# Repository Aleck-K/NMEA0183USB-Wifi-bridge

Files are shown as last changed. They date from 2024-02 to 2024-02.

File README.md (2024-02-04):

NMEA0183USB-Wifi-bridge on ESP8266 microcontroller
  
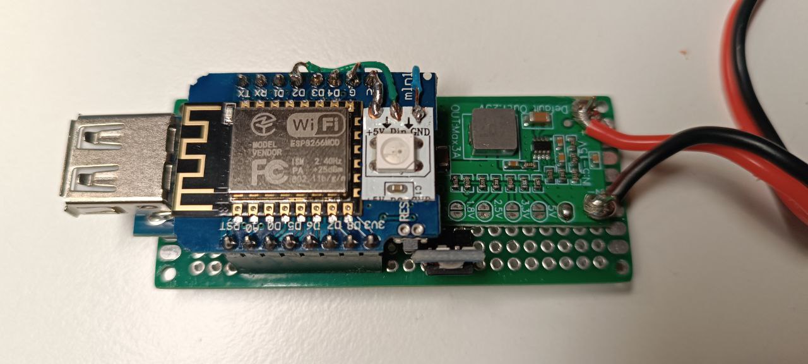
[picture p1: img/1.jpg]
</td>

The idea behind the project is to use perhaps the cheapest Matsutec AR-10 AIS receiver on the market to transmit NMEA messages to Navionics. Navionics perfectly supports receiving messages via a Wifi network. The device is a bridge between the Matsutec AR-10 (or any other USB device running on the CH340 chip) and WiFi. In addition, NMEA messages received from USB are duplicated into the USB port of the microcontroller board; the device can be connected to a computer to transmit messages to, for example, OpenCPN. Also, messages coming to the USB of the microcontroller are sent to WiFI.

The project code is based on the code of the following projects:

https://github.com/alvra/nmea-bridge - read the annotation to understand all the capabilities of the device.
https://github.com/UNBIduino/USBHostSeildWithCH340 - driver for CH340 chip

To assemble the device, no special knowledge or skills in electronics are required. The device is assembled from ready-made components:
1. ESP8266 WeMos D1 Mini V2 (ESP-12)
2. Mini USB Host Shield
3. Power converter 12-5v TZT 3A
4. Power converter 5-3.3v GSMIN AMS1117 800mA
5. Breadboard 3x7cm
6. Optional: 1 addressable LED WS2812B or similar
7. 4 screws 2.2x4.5 fastening the board, 4 screws 4.5x20 for the case

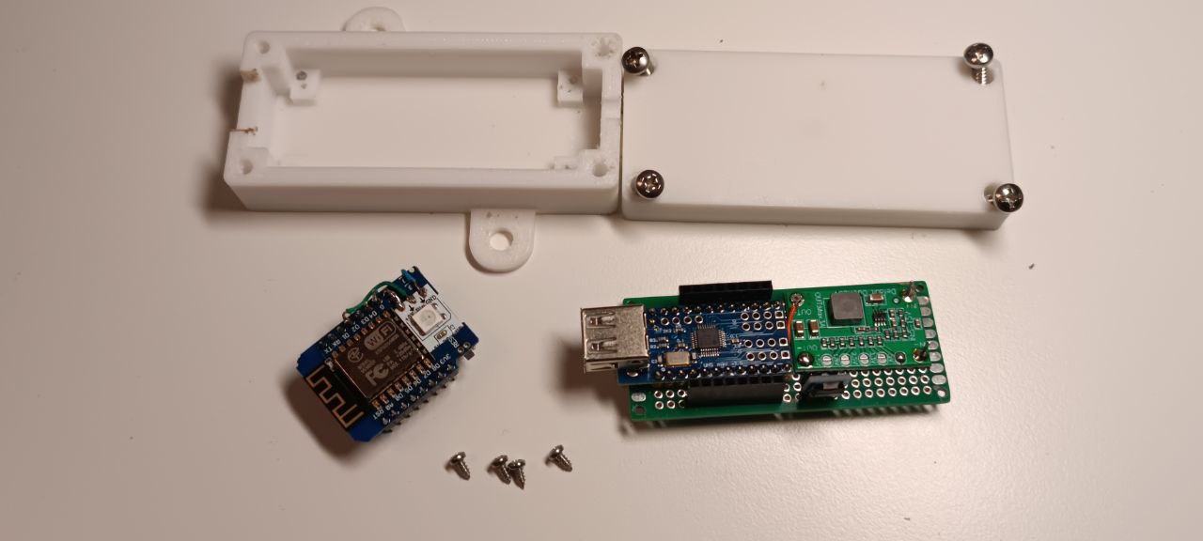
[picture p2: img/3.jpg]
</td>
 
Connection diagram here:
https://oshwlab.com/aleck1/new-project
Please note the following during assembly:
* it is necessary to supply 5v power to the VBUS pin of the Mini USB Host Shield board, otherwise the AR-10 will not work. Most likely, to do this, you need to cut the track going to the VBUS pin and solder the conductor to the 5v power supply directly to the pin. Read more about the problem and its solution here: https://www.hackster.io/usini/plug-any-usb-device-on-an-esp8266-e0ca8a (Fix Powering Issues)
* Mini USB Host Shield is placed asymmetrically on a 3x7cm breadboard. I recommend moving it one row to the right. This will provide more space for conductors to WEMOS. The case is also designed with this displacement in mind.
* In order for everything to fit on a 3x7cm breadboard, the Mini USB Host Shield must be placed on the first row of the board
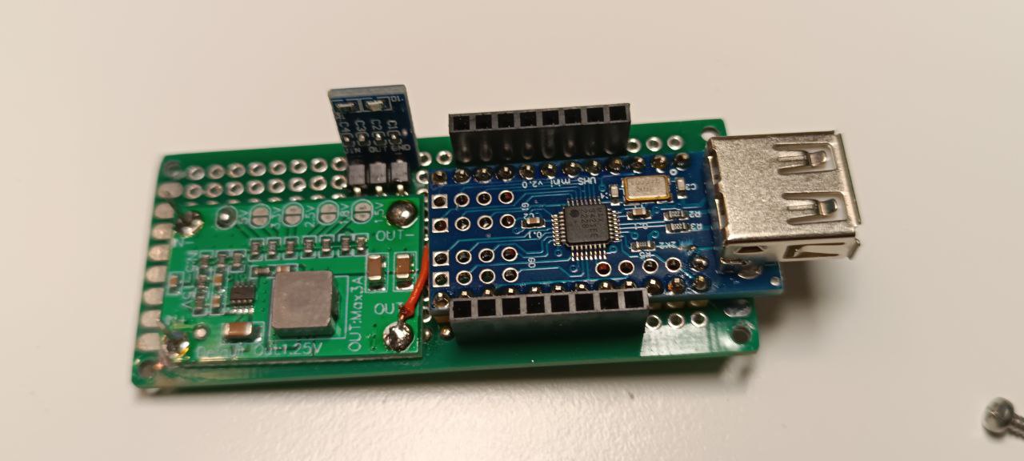
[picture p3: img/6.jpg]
</td>
* The ESP8266 WeMos D1 Mini microcontroller is placed ABOVE the Mini USB Host board on a high comb starting from the 4th row. Typically this comb comes with WeMos D1
* Although the device works without a 5-3.3v power converter, it is still better to use it, because the WEMOS power on the 3.3v pin may not be enough for stable operation

An optional WS2812B addressable LED is used to provide better visibility into device operating status. It can be glued directly to the WeMos D1 board, control pin D2. It signals the following:
* red: USB initialization or reading error
* blue: double blinking every 15 seconds - working in access point mode, single blinking - working in wifi client mode, constantly on - wifi initialization error
* green: NMEA message received and processed via USB
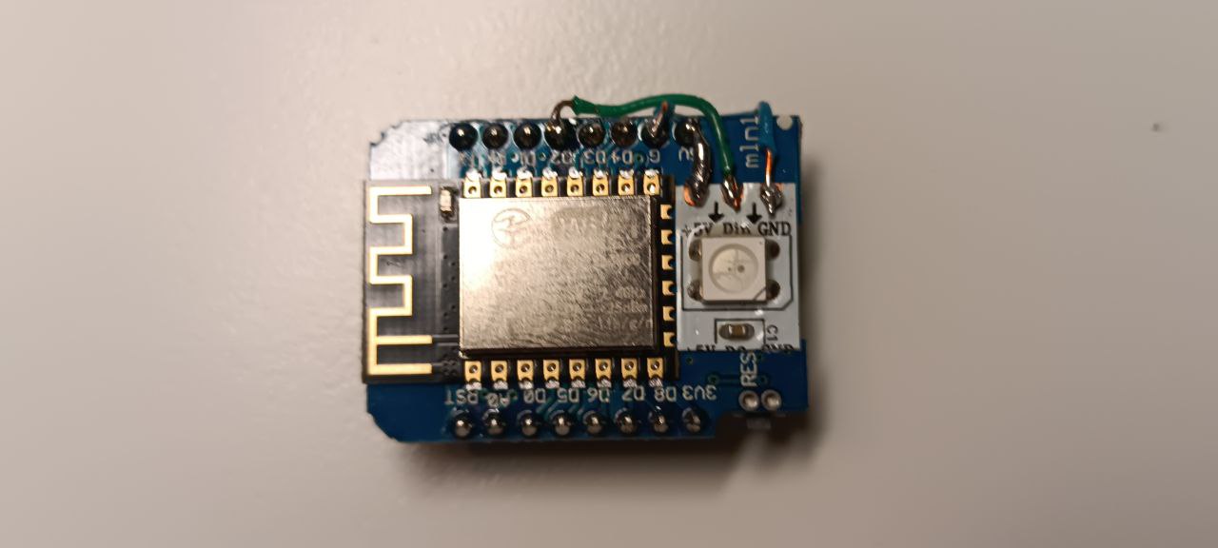
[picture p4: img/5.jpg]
</td>

You can do without an addressable LED. In this case, the indication is by the built-in LED: double blinking every 15 seconds - working in access point mode, single blinking - working in wifi client mode, constantly lit - wifi initialization error. Be sure to comment out (delete) the line in the sketch #define RGB_LED to enable indication mode with built-in LED.

Please note: The current version does not support hot plugging of the AR-10 to USB. AIS must be connected before the device is powered on.

Case layout for printing on a 3D printer in the Box_design catalog. Ears are provided for surface mounting.

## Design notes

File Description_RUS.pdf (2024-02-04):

NMEA0183USB-Wifi-bridge на микроконтроллере ESP8266

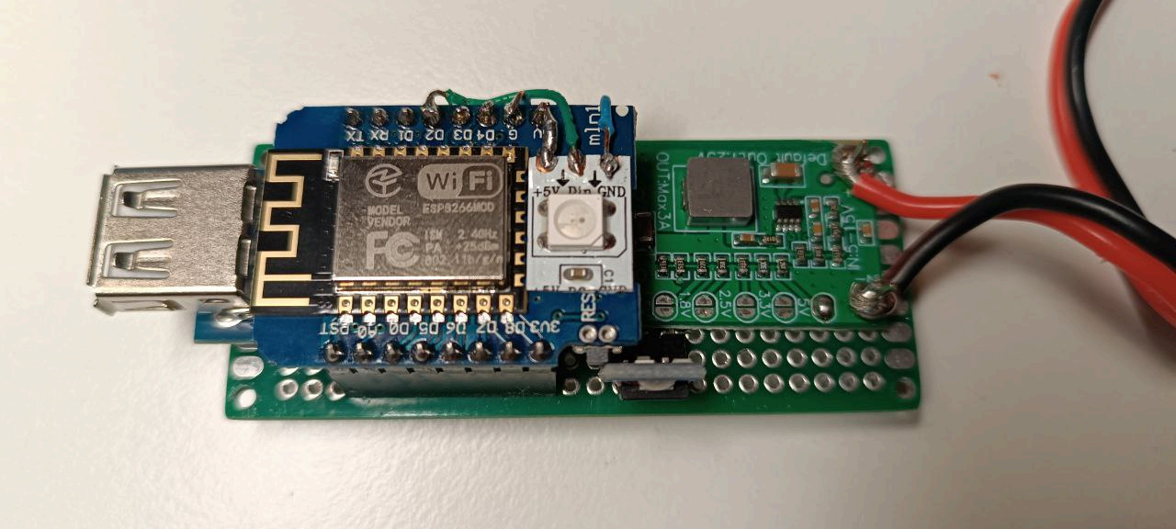
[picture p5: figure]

Идея проекта - использовать, пожалуй, самый дешевый на рынке AIS приемник Matsutec AR-10 для передачи сообщений NMEA в Navionics. Навионикс отлично поддерживает получение сообщений через сеть Wifi. Устройство является мостом между Matsutec AR-10 (или любым другим USB устройством, работающем на чипе CH340) и WiFi. Кроме того, сообщения NMEA, полученные с USB, дублируются в USB порт платы микроконтроллера, устройство может быть подключено к компьютеру для передачи сообщений в, например, OpenCPN. Также сообщения, приходящие в USB микроконтроллера, пересылаются в WiFI.

Код проекта основан на коде следующих проектов: https://github.com/alvra/nmea-bridge - прочитайте анотацию, чтобы понять все возможности устройства.
https://github.com/UNBIduino/USBHostSeildWithCH340 - драйвер для чипа CH340

Для сборки устройства не требуется особых знаний и навыков в электронике. Устройство собирается из готовых компонентов:
1. ESP8266 WeMos D1 Mini V2 (ESP-12)
2. Mini USB Host Shield
3. Конвертер питания 12-5v TZT 3A
4. Конвертер питания 5-3.3v GSMIN AMS1117 800мА
5. Макетная плата 3х7см
6. Опционально: 1 адресный светодиод WS2812B или аналогичный
7. 4 шурупа 2.2х4.5 крепление платы, 4 шурупа 4.5х20 для корпуса

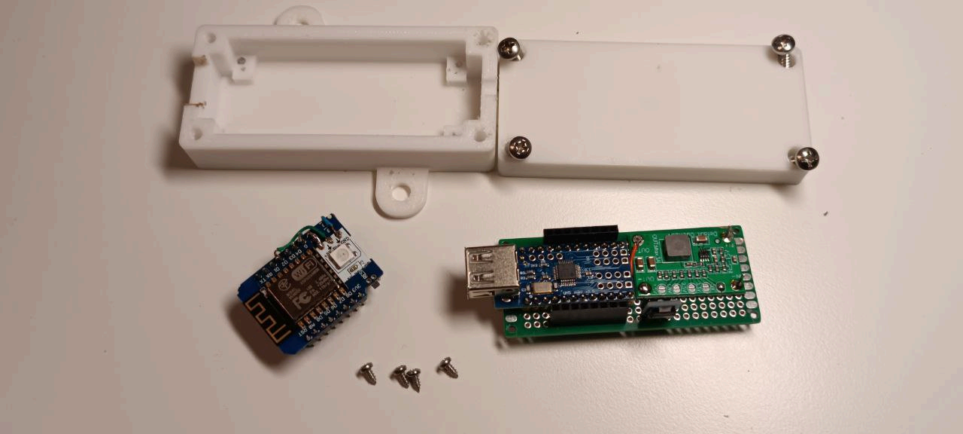
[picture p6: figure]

Схема соединений здесь:
https://oshwlab.com/aleck1/new-project
При сборке необходимо учесть следующее:
- необходимо подать питание 5v на пин VBUS платы Mini USB Host Shield, иначе AR-10 работать не будет. Скорее всего, для этого необходимо перерезать дорожку, идущую к пину VBUS и припаять проводник к 5v питанию напрямую на пин. Подробнее о проблеме и ее решении здесь: https://www.hackster.io/usini/plug-any-usb-device-on-an-esp8266-e0ca8a (Fix Powering Issues)
- Mini USB Host Shield размещается на макетной плате 3х7см несимметрично. Рекомендую сдвинуть его на один ряд вправо. Так будет больше места для проводников к WEMOS. Корпус тоже спроектирован с учетом такого смещения.
- Чтобы все поместилось на макетную плату 3х7см, размещать Mini USB Host Shield надо с первого ряда платы

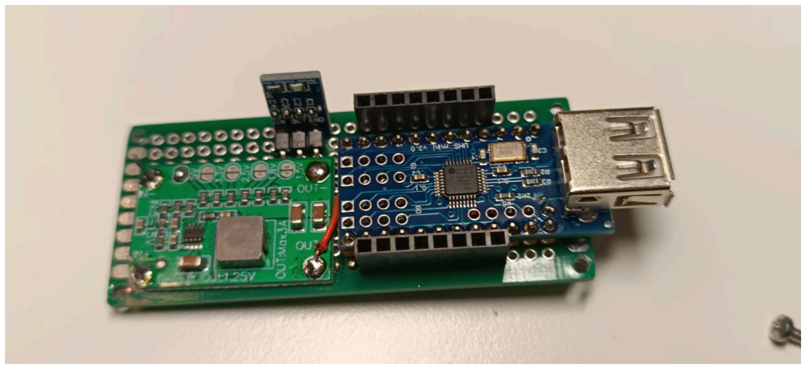
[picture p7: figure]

- Микроконтроллер ESP8266 WeMos D1 Mini размещается НАД платой Mini USB Host на высокой гребенке начиная с 4 ряда. Обычно такая гребенка идет в комплекте с WeMos D1

- Хотя устройство работает и без Конвертера питания 5-3.3v, лучше все же его использовать, т.к. мощности WEMOS на пине 3.3v может не хватать для стабильной работы

Опциональный адресный светодиод WS2812B используется для лучшего представления о статусе работы устройства. Его можно приклеить прямо на плату WeMos D1, управляющий пин D2. Он сигнализирует следующее:
- красный: ошибка инициализации или чтения USB
- синий: двойное мигание раз в 15 сек - работа в режиме точки доступа, одиночное мигание - работа в режиме wifi клиента, горит постоянно - ошибка инициализации wifi
- зеленый: получено и обработано сообщение NMEA по USB

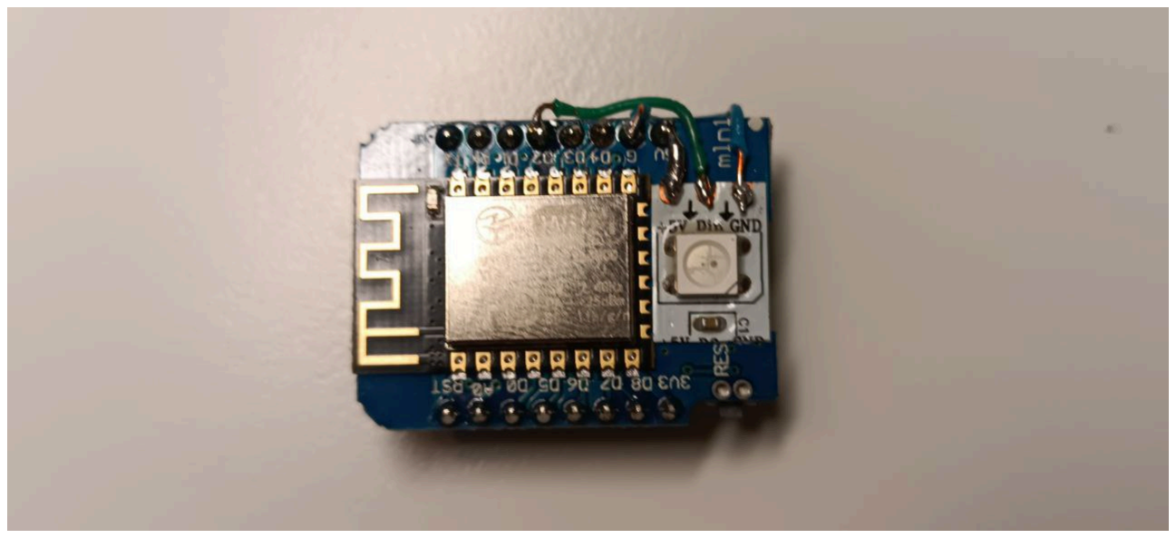
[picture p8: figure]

Можно обойтись без адресного светодиода. В этом случае индикация происходит встроенным светодиодом: двойное мигание раз в 15 сек - работа в режиме точки доступа, одиночное мигание - работа в режиме wifi клиента, горит постоянно - ошибка инициализации wifi Обязательно нужно закомментировать (удалить) строку в скетче #define RGB_LED для включения режима индикации встроенным светодиодом.

Обратите внимание: в текущей версии не реализовано горячее подключение AR-10 к USB. AIS должен быть подключен до включения питания устройства.

Макет корпуса для печати на 3D принтере в каталоге Box_design. Предусмотрены ушки для крепления на поверхность.

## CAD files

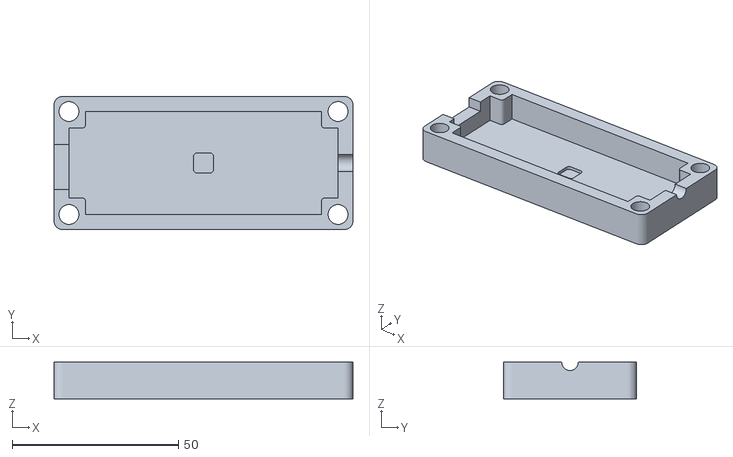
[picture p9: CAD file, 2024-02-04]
Box_design/New-USBAIS-top-UBS-topPart.stl
90.0 x 40.0 x 11.0

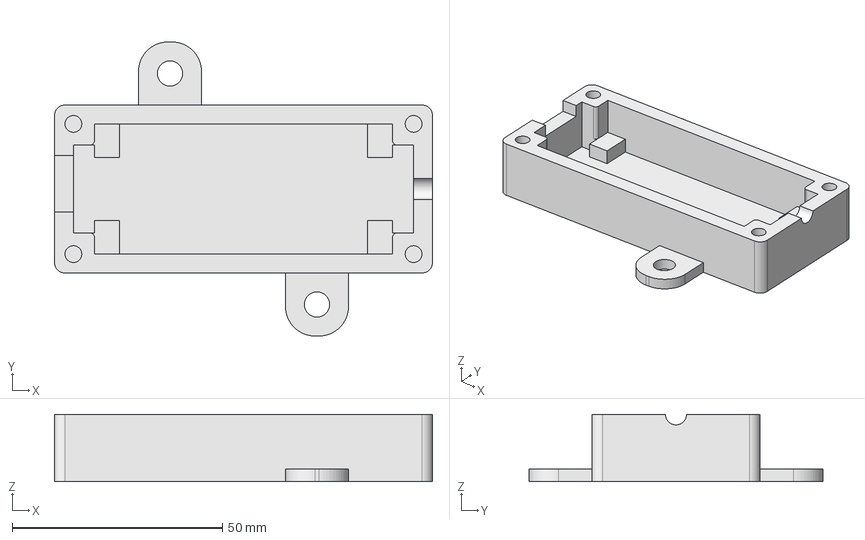
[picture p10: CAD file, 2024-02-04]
Box_design/New-USBAIS.FCStd
90.0 x 70.0 x 16.0 mm

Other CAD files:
Box_design/New-USBAIS-top.FCStd
Box_design/New-USBAIS-UBS-bottomPart.stl

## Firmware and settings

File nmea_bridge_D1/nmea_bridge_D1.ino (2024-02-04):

#include <Arduino.h>
#include <EEPROM.h>
#include <ESP8266WiFi.h>
#include <WiFiUdp.h>
#include <ESP8266WebServer.h>
#include <ESP8266mDNS.h>
#include <WebSocketsServer.h>
#include <DNSServer.h>
#include "cdcch340.h"
#include <usbhub.h>
#include "FastLED.h"          // library for working with LED strip

// Satisfy the IDE, which needs to see the include statment in the ino too.
#ifdef dobogusinclude
#include <spi4teensy3.h>
#endif
#include <SPI.h>

extern "C" {
    #include "user_interface.h"
    uint16 readvdd33(void);
}

// global macros utils

//#define TESTING

#define DEBUG

#define DEBUG_SERIAL            Serial

#ifdef DEBUG
  #define DEBUG_PRINT(x)        DEBUG_SERIAL.print(x)
  #define DEBUG_PRINTLN(x)      DEBUG_SERIAL.println(x)
#else
  #define DEBUG_PRINT(x)        {}
  #define DEBUG_PRINTLN(x)      {}
#endif

#define min(x, y) ((x < y) ? x : y)

// hardware layout

#define CONFIG_EEPROM_ADDRESS   100

#define WIFI_SIGNAL_POWER       20.5     // min: 0 - max: 20.5 dBm

#define BOOT_MODE_BUTTON_PIN    0

#define RESET_CONFIG_THRESHOLD  5000  // in milliseconds

// Indicator layout

// builin led
#define INDICATOR_LED_PIN       2
#define INDICATOR_LED_ON        0
#define INDICATOR_LED_OFF       1
//extra RGB LED indicator
//Red - failure alarm
//Blue - wifi status
//Green - USB message activity
#define RGB_LED                 1   //comment this line if you don't have one
#ifdef RGB_LED
  #define RGB_LED_PIN           D2  // where RGB led connected
#endif



// configuration

#define MAX_WIFI_SSID_SIZE      33
#define MAX_WIFI_PASSWORD_SIZE  33
#define MAX_MDNS_HOSTNAME_SIZE  33

#define ENABLE_WEBSOCKET_LOG

enum WifiMode: uint8_t {
    station = 1,
    access_point = 2,
};

enum TransmitMode: uint8_t {
    broadcast = 1,
    multicast = 2,
    unicast = 3,
};

#define BAUDRATE_OPTION_COUNT  4
uint32_t baudrate_options[BAUDRATE_OPTION_COUNT + 1] = {
    0,  // not an option, used to distinguish from undefined
    4800,
    9600,
    38400,
    115200
};

// The serial device on which this device receives NMEA sentences.
#define SERIAL_RX   Serial

// The serial device on which this device transmits NMEA sentences.
#define SERIAL_TX   Serial


// Set to 1 if the RX and TX serial ports are the same one.
#define SERIAL_SAME 1  // TODO automatic

struct Configuration {
    WifiMode wifi_mode;
    char wifi_ssid[MAX_WIFI_SSID_SIZE];
    char wifi_password[MAX_WIFI_PASSWORD_SIZE];
    IPAddress static_ip_address;
    char mdns_hostname[MAX_MDNS_HOSTNAME_SIZE];
    TransmitMode tx_mode;
    IPAddress tx_address;
    uint16_t tx_port;
    uint16_t rx_port;
    uint8_t tx_baudrate;
    uint8_t rx_baudrate;
    uint8_t led_brightness;
} config;

const char* display_wifi_mode(WifiMode mode) {
    if (mode == WifiMode::station) {
        return "Station";
    } else {
        return "Access Point";
    }
}

const char* display_tx_mode(TransmitMode mode) {
    if (mode == TransmitMode::broadcast) {
        return "Broadcast";
    } else if (mode == TransmitMode::multicast) {
        return "Multicast";
    } else {
        return "Unicast";
    }
}

struct Configuration default_config = {
    // wifi_mode
    WifiMode::access_point,
    // wifi_ssid
    "NMEA",
    // wifi_password
    "1234567890",
    // static_ip_address
    INADDR_ANY,
    // mdns_hostname
    "nmea_bridge",
    // tx_mode
    TransmitMode::broadcast,
    // tx_address
    INADDR_ANY,
    // tx_port
    10110,
    // rx_port
    10110,
    // tx_baudrate (4800)
    1,
    // rx_baudrate (4800)
    1,
    // brightness of LED indicator if used
    100,
};


// global values

#define HTTP_PORT       80
#define WEBSOCKET_PORT  81
#define DNS_PORT        53

#define WIFI_ACCESS_POINT_CHANNEL 6
#define WIFI_ACCESS_POINT_MAX_CONNECTIONS 4  // max 8
#define WIFI_ACCESS_POINT_DEVICE_IP  IPAddress(10, 1, 1, 1)
#define WIFI_ACCESS_POINT_GATEWAY_IP IPAddress(10, 1, 1, 1)
#define WIFI_ACCESS_POINT_SUBNET_IP  IPAddress(255, 255, 255, 0)

bool inConfigMode = false;
#ifdef RGB_LED
  uint8_t led_state_r = 0;
  uint8_t led_state_g = 0;
  uint8_t led_state_b = 0;
  struct CRGB leds[1];  //we have 1-led strip
  #define rgbled leds[0];
#endif
uint8_t indicator_led_state;
WifiMode effective_wifi_mode;
char effective_wifi_ssid[MAX_WIFI_SSID_SIZE];
IPAddress effective_tx_address;
uint16_t nmea_sentences_received = 0;
uint16_t nmea_sentences_sent = 0;
bool is_network_config_changed = false;

#define UDP_SENTENCE_BUFFER_SIZE 64

#define HTTP_RESPONSE_BUFFER_SIZE 4000
char http_response_buffer[HTTP_RESPONSE_BUFFER_SIZE + 1];
uint16_t http_response_buffer_filled = 0;
#define HTTP_RESPONSE_BUFFER_REMAINING \
    (HTTP_RESPONSE_BUFFER_SIZE - http_response_buffer_filled)

/* The buffer should be long enough for about two sentences
** so we can handle the case where a (single) newline is lost.
*/
#define NMEA_SENTENCE_BUFFER_SIZE 100
char nmea_sentence_buffer[NMEA_SENTENCE_BUFFER_SIZE + 1];
uint8_t nmea_sentence_buffer_filled = 0;  // number of chars in buffer


/* USB Part 
*/
uint8_t usb_task_state = USB_STATE_DETACHED;
/* USB state machine states 
#define USB_STATE_MASK                                      0xf0
#define USB_STATE_DETACHED                                  0x10
#define USB_DETACHED_SUBSTATE_INITIALIZE                    0x11
#define USB_DETACHED_SUBSTATE_WAIT_FOR_DEVICE               0x12
#define USB_DETACHED_SUBSTATE_ILLEGAL                       0x13
#define USB_ATTACHED_SUBSTATE_SETTLE                        0x20
#define USB_ATTACHED_SUBSTATE_RESET_DEVICE                  0x30
#define USB_ATTACHED_SUBSTATE_WAIT_RESET_COMPLETE           0x40
#define USB_ATTACHED_SUBSTATE_WAIT_SOF                      0x50
#define USB_ATTACHED_SUBSTATE_WAIT_RESET                    0x51
#define USB_ATTACHED_SUBSTATE_GET_DEVICE_DESCRIPTOR_SIZE    0x60
#define USB_STATE_ADDRESSING                                0x70
#define USB_STATE_CONFIGURING                               0x80
#define USB_STATE_RUNNING                                   0x90
#define USB_STATE_ERROR                                     0xa0
*/

class CH340Async : public CH340AsyncOper
{
  public:
    uint8_t OnInit(CH340 *pch340);
    uint8_t OnRelease(CH340 *pch340);
};

uint8_t CH340Async::OnInit(CH340 *pch340)
{
  uint8_t rcode = 0;
  linecoding lc;
  lc.msr = 0;
  lc.baud_rate = 38400; // fixed baud rate for AR-10;
  lc.lcr = CH340_LCR_ENABLE_RX | CH340_LCR_ENABLE_TX | CH340_LCR_CS8;
  rcode = pch340->Configure(&lc);
  if (rcode) {
    force_alarm_led_on();
    DEBUG_PRINT("Configure failed");
    DEBUG_PRINTLN("rcode");
    return rcode;
  }

#ifdef TESTING
/*
  rcode = pch340->GetModemStatus(&lc);
  if (rcode) {
    force_alarm_led_on();
    DEBUG_PRINT("GetModemStatus");
    DEBUG_PRINTLN("rcode");
  }

  DEBUG_PRINT("mcr: ");
  DEBUG_PRINTLN(lc.msr, HEX);

  rcode = pch340->SetModemControl(lc.lcr);
  if (rcode)
    ErrorMessage<uint8_t>(PSTR("SetModemControl"), rcode);

  rcode = pch340->DtrRts(&lc, 1);
  if (rcode)
    ErrorMessage<uint8_t>(PSTR("DTR/RTS on"), rcode);
  delay(500);
  rcode = pch340->DtrRts(&lc, 0);
  if (rcode)
    ErrorMessage<uint8_t>(PSTR("DTR/RTS off"), rcode);
*/
#endif
  return rcode;
}

/**
   Possible clean op when releasing the connection.
*/
uint8_t CH340Async::OnRelease(CH340 *pch340)
{
  uint8_t rcode = 0;
  return rcode;
}

USB              Usb;
USBHub         Hub(&Usb);
CH340Async       ch340Async;
CH340            ch340(&Usb, &ch340Async);
unsigned int  init_timer=0;  //timer to reInit USB

#define MAX_PCKT_SIZE 32  //TODO USB packet size. This value must be received from USB device!
uint8_t buf[MAX_PCKT_SIZE+1]; 
char usb_sentence_buffer[(NMEA_SENTENCE_BUFFER_SIZE + 1)*2];
uint8_t usb_sentence_buffer_filled = 0;  // number of chars in buffer

ESP8266WebServer    http_server(HTTP_PORT);
WiFiUDP             udp_server;
DNSServer           dns_server;
#ifdef ENABLE_WEBSOCKET_LOG
    WebSocketsServer    websocket_server(WEBSOCKET_PORT);
#endif


// cache static files "forever" (about a year)
#define STATIC_FILE_CACHE_TIME  31536000  // in seconds
#define JS_CONTENT_TYPE         "application/javascript"
#define CSS_CONTENT_TYPE        "text/css"

/* Create a request handler for static files.
*/
#define STATIC_FILE_REQUEST_HANDLER(content_type, content) \
    { \
        if (captive_portal()) {return;} \
        http_server.sendHeader( \
            "Cache-Control", \
            String("max-age=") + STATIC_FILE_CACHE_TIME, \
            true); \
        http_server.send(200, content_type, content); \
    }



// forward declarations

void send_info_page_response();
void send_config_form_response();
void nmea_log_page_response();
void send_css_style_response();
void send_404_not_found_response();

void update_mdns_hostname();
void update_tx_config();
void update_rx_config();
void update_tx_baudrate();
void update_rx_baudrate();

void set_indicator_led_on();
void set_indicator_led_off();
void force_indicator_led_on();
void force_indicator_led_off();
void toggle_indicator_led();
void long_indicator_blink();
void update_indicator_slow_blink();
void update_indicator_double_blink();
bool blink_while_pressing_mode_button();
void blink_while_connecting_wifi();

String get_uptime_display();
IPAddress get_device_ip_address();
IPAddress gateway_address(IPAddress addr);
IPAddress subnet_address(IPAddress addr);

void load_config_from_eeprom(Configuration &new_config);
void store_config_to_eeprom(Configuration new_config);
void fix_config();



#include "html_fragments.cpp"  // TODO inherit WEBSOCKET_PORT
#include "css_fragments.cpp"
#include "js_fragments.cpp"

extern const String html_start;
extern const String html_end;
extern const String html_log_content;
extern const String css_style;
extern const String js_log_script;



/**********************
**  MAIN EVENT LOOP  **
**********************/

void setup() {

    EEPROM.begin(512);
    load_config_from_eeprom(config);
    fix_config();

    #ifdef RGB_LED
      pinMode(RGB_LED_PIN, OUTPUT);
      LEDS.setBrightness(config.led_brightness); // limit maximum brightness
      LEDS.addLeds<WS2812B, RGB_LED_PIN, GRB>(leds, 1); // settings for our strip (strip on WS2811, WS2812, WS2812B)
      //show rainbow at start
      for (int ihue = 0 ; ihue < 255; ihue++ ) {
        leds[0] = CHSV(ihue, 255, 255);
        LEDS.show();
        delay(20);
      }
      leds[0] = CHSV(0, 0, 0);
      force_alarm_led_on(); // Fire alarm while startup
    #endif

    nmea_sentence_buffer_filled = 0;

    SERIAL_RX.begin(baudrate_options[config.rx_baudrate]);
    #if !SERIAL_SAME
      SERIAL_TX.begin(baudrate_options[config.tx_baudrate]);
    #endif

    #ifdef DEBUG
      DEBUG_SERIAL.setDebugOutput(true);
    #endif

    // wait for serial to connect
    delay(10);

    if (Usb.Init() == -1)  {  //try to Init USB device
        DEBUG_PRINTLN("OSC did not start.");
    } else {
        force_alarm_led_off();
    }

    // give the user a chance to press the boot-mode button after reset
    delay(1000);

    pinMode(INDICATOR_LED_PIN, OUTPUT);
    #ifdef RGB_LED
      digitalWrite(INDICATOR_LED_PIN, INDICATOR_LED_OFF);
    #endif
    force_indicator_led_off();

    effective_wifi_mode = config.wifi_mode;
    pinMode(BOOT_MODE_BUTTON_PIN, INPUT_PULLUP);
    if (digitalRead(BOOT_MODE_BUTTON_PIN) == LOW) {
        bool exceeded_threshold = blink_while_pressing_mode_button();
        if (exceeded_threshold) {
            DEBUG_PRINTLN("Resetting configuration to default");
            long_indicator_blink();
            config = default_config;
            store_config_to_eeprom(config);
            // change state to match new config
            update_tx_baudrate();
            update_rx_baudrate();
            effective_wifi_mode = config.wifi_mode;
        } else {
            DEBUG_PRINTLN("Forcing access point mode");
            effective_wifi_mode = WifiMode::access_point;
            inConfigMode = true;
        }
    }

    // WiFi.hostname(config.mdns_hostname);

    #ifdef WIFI_SIGNAL_POWER
        WiFi.setOutputPower(WIFI_SIGNAL_POWER);
    #endif

    strlcpy(effective_wifi_ssid, config.wifi_ssid, MAX_WIFI_SSID_SIZE);
    WiFi.setSleepMode(WIFI_NONE_SLEEP);
    if (effective_wifi_mode == WifiMode::access_point) {
        DEBUG_PRINT("starting new wifi network: ");
        DEBUG_PRINTLN(effective_wifi_ssid);

        WiFi.mode(WIFI_AP);
        WiFi.softAPConfig(
            (config.static_ip_address.isSet() ?
                config.static_ip_address : WIFI_ACCESS_POINT_DEVICE_IP),
            WIFI_ACCESS_POINT_GATEWAY_IP,
            WIFI_ACCESS_POINT_SUBNET_IP);
        WiFi.softAP(effective_wifi_ssid, config.wifi_password, WIFI_ACCESS_POINT_CHANNEL, WIFI_ACCESS_POINT_MAX_CONNECTIONS);
        //WiFi.softAP(effective_wifi_ssid, "1234567890", WIFI_ACCESS_POINT_CHANNEL, WIFI_ACCESS_POINT_MAX_CONNECTIONS);

        // wait for the ip address to be available
        delay(500);

        // setup dns for captive portal
        dns_server.setErrorReplyCode(DNSReplyCode::NoError);
        dns_server.start(DNS_PORT, "*", WiFi.softAPIP());
    } else {
        DEBUG_PRINT("connecting to existing wifi network: ");
        DEBUG_PRINTLN(effective_wifi_ssid);

        WiFi.mode(WIFI_STA);
        if (config.static_ip_address.isSet()) {
            WiFi.config(config.static_ip_address, gateway_address(config.static_ip_address), subnet_address(config.static_ip_address));
        } else {
            // use DHCP, which is the default
        }

        WiFi.begin(effective_wifi_ssid, config.wifi_password);
        blink_while_connecting_wifi();
    }
    DEBUG_PRINTLN("done setting up wifi");

    // start udp server
    udp_server.begin(config.rx_port);

    // start mDNS server
    if (config.mdns_hostname[0] != '\0') {
        // TODO mDNS doesnt work in station mode

        DEBUG_PRINT("starting MDNS: http://");
        DEBUG_PRINT(config.mdns_hostname);
        DEBUG_PRINTLN(".local/");
        MDNS.begin(config.mdns_hostname);
    }

    // start web server
    DEBUG_PRINTLN("starting http server");
    http_response_buffer[HTTP_RESPONSE_BUFFER_SIZE] = '\0';
    http_server.on("/", send_info_page_response);
    http_server.on("/config", send_config_form_response);
    #ifdef ENABLE_WEBSOCKET_LOG
        http_server.on("/log", nmea_log_page_response);
        http_server.on("/log_script.js", send_js_log_script);
    #endif
    http_server.on("/style.css", send_css_style_response);
    http_server.onNotFound(send_404_not_found_response);
    http_server.begin();

    #ifdef ENABLE_WEBSOCKET_LOG
        DEBUG_PRINTLN("starting websocket server");
        websocket_server.begin();
        websocket_server.onEvent(handle_websocket_event);
    #endif

    // determine transmit address
    update_tx_config();

    DEBUG_PRINT("transmit: udp://");
    DEBUG_PRINT(effective_tx_address.toString());
    DEBUG_PRINT(":");
    DEBUG_PRINT(config.tx_port);
    DEBUG_PRINT("/   (");
    DEBUG_PRINT(display_tx_mode(config.tx_mode));
    DEBUG_PRINTLN(")");

    DEBUG_PRINT("receive: udp://");
    DEBUG_PRINT(get_device_ip_address().toString());
    DEBUG_PRINT(":");
    DEBUG_PRINT(config.rx_port);
    DEBUG_PRINTLN("/");
    DEBUG_PRINT("PWD: ");
    DEBUG_PRINTLN(config.wifi_password);

    #ifdef RGD_LED
      force_alarm_led_off
    #endif
}

void loop() {

    handle_usb_event();
    yield();

    handle_serial_event();
    yield();

    handle_udp_event();
    yield();

    http_server.handleClient();
    yield();

    #ifdef ENABLE_WEBSOCKET_LOG
        websocket_server.loop();
        yield();
    #endif

    MDNS.update();
    yield();

    dns_server.processNextRequest();
    yield();

    // use indicator led to show connection status
    #ifdef RGB_LED
      update_msg_led();
    #endif
    if (effective_wifi_mode == WifiMode::access_point) {
        update_indicator_double_blink();
    } else {
        if (!WiFi.isConnected()) {
            update_indicator_slow_blink();
        } else {
            set_indicator_led_on();
        }
    }

    return;
}



/*********************
**  EVENT HANDLERS  **
*********************/
void handle_usb_event() {
  
  Usb.Task();

  usb_task_state = Usb.getUsbTaskState();
  if ( usb_task_state != USB_STATE_RUNNING ) {
    force_alarm_led_on();
    DEBUG_PRINTLN(Usb.getUsbTaskState());
    if (init_timer==0)  { init_timer = millis(); } else {
      if (millis()-init_timer>5000) {
        DEBUG_PRINTLN("reinit");
        init_timer=0;
        if (Usb.Init() == -1)
          DEBUG_PRINTLN("OSC did not start.");
        }
        delay( 200 );
    }
  } else {
    force_alarm_led_off();
  }
  if (ch340.isReady()) {
    uint8_t  rcode;
    
    uint16_t rcvd = MAX_PCKT_SIZE;
    while (rcvd>0) {
      for (uint8_t i = 0; i < MAX_PCKT_SIZE+1; i++)
        buf[i] = 0;
      uint16_t rcvd = MAX_PCKT_SIZE;
      rcode = ch340.RcvData(&rcvd, buf);
      if (rcode && rcode != hrNAK) {
        DEBUG_PRINT("Ret ");  DEBUG_PRINTLN(rcode);
        force_alarm_led_on();   
      }
      if (rcvd > 0) {
        //DEBUG_PRINTLN((char*)(buf));
        strncpy(usb_sentence_buffer + usb_sentence_buffer_filled, (char*)buf, rcvd);
        usb_sentence_buffer_filled +=rcvd;
        if (usb_sentence_buffer_filled >= NMEA_SENTENCE_BUFFER_SIZE) {
            DEBUG_PRINTLN("usb sentence buffer overflow");
            // A newline must have been lost since at least two sentences
            // should fit in the buffer, so send all buffered data immedately
            // to let the client decide how to handle this.
            usb_sentence_buffer[NMEA_SENTENCE_BUFFER_SIZE] = '\n';
            usb_sentence_buffer_filled = NMEA_SENTENCE_BUFFER_SIZE + 1;
        }
        if (usb_sentence_buffer[usb_sentence_buffer_filled-1] == '\n') {
          force_msg_led_on(); 
          handle_outgoing_sentence( usb_sentence_buffer, usb_sentence_buffer_filled );
          transmit_incoming_over_serial( usb_sentence_buffer, usb_sentence_buffer_filled );
          //DEBUG_PRINT(usb_sentence_buffer);
          usb_sentence_buffer_filled = 0;
          for (uint8_t i = 0; i < (NMEA_SENTENCE_BUFFER_SIZE + 1)*2; i++)
              usb_sentence_buffer[i] = 0;
          break;
        }
        delay(5);
      } else { break; }
    }
  }
}


void handle_serial_event() {
    // on incoming data over the hardware serial port
    int serial_character_int;
    char serial_character;
    while (1) {
        serial_character_int = SERIAL_RX.read();

        if (serial_character_int < 0) {
            // no more data available
            return;
        }

        serial_character = (char)serial_character_int;

        // TODO sometimes this gives a large number of zero bytes
        // TODO then we also don't get the extra newline

        nmea_sentence_buffer[nmea_sentence_buffer_filled] = serial_character;
        nmea_sentence_buffer_filled ++;
        if (serial_character == '\n') {

        } else if (nmea_sentence_buffer_filled >= NMEA_SENTENCE_BUFFER_SIZE) {
            DEBUG_PRINTLN("nmea sentence buffer overflow");
            // A newline must have been lost since at least two sentences
            // should fit in the buffer, so send all buffered data immedately
            // to let the client decide how to handle this.
            nmea_sentence_buffer[NMEA_SENTENCE_BUFFER_SIZE] = '\n';
            nmea_sentence_buffer_filled = NMEA_SENTENCE_BUFFER_SIZE + 1;
        } else {
            continue;
        }
        handle_outgoing_sentence(
            nmea_sentence_buffer, nmea_sentence_buffer_filled);
        nmea_sentence_buffer_filled = 0;
    }
}

void handle_udp_event() {
    // on incoming data over the network udp connection
    int packet_size = udp_server.parsePacket();
    char buffer[UDP_SENTENCE_BUFFER_SIZE + 2];
    if (packet_size) {
        while (1) {
            size_t length = udp_server.read(buffer, UDP_SENTENCE_BUFFER_SIZE);
            if (length <= 0) {
                return;
            }
            if (buffer[length - 1] != '\n') {
                // Add newline terminator if not not yet present.
                buffer[length] = '\n';
                length ++;
            }
            handle_incoming_sentence(buffer, length, "udp");
        }
    }
}

#ifdef ENABLE_WEBSOCKET_LOG
    void handle_websocket_event(uint8_t num, WStype_t type, uint8_t * payload, size_t length) {
        // on incoming data over the network websocket connection

        // TODO handle text fragments, although nmea sentences are very short
        // https://github.com/Links2004/arduinoWebSockets/blob/master/examples/esp8266/WebSocketServerFragmentation/WebSocketServerFragmentation.ino

        if (type == WStype_TEXT) {
            if ((char)payload[length - 1] != '\n') {
                // Add newline terminator if not not yet present.
                String sentence = (char *)payload;  // TODO not pretty
                sentence += '\n';
                payload = (uint8_t*)sentence.c_str();
                length ++;
            }
            handle_incoming_sentence((char *)payload, length, "ws");
        }
    }
#endif


void handle_incoming_sentence(char *sentence, size_t length, char *source) {
    /* data is sent into the nmea device
    **   sentence: always includes the newline and must be newline terminted
    */
    transmit_incoming_over_serial(sentence, length);

    #ifdef ENABLE_WEBSOCKET_LOG
        transmit_incoming_over_websocket(sentence, length, source);
    #endif

    nmea_sentences_sent ++;
} 

void handle_outgoing_sentence(char *sentence, size_t length) {
    /* data is received from the nmea device
    **   sentence: always includes the newline and must be newline terminted
    */
    transmit_outgoing_over_udp(sentence, length);

    #ifdef ENABLE_WEBSOCKET_LOG
        transmit_outgoing_over_websocket(sentence, length);
    #endif

    nmea_sentences_received ++;
}


void transmit_incoming_over_serial(char *sentence, size_t length) {
    SERIAL_TX.write(sentence, length);
}
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
